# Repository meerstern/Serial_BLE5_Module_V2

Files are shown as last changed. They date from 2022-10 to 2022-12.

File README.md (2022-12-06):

# BLE5モジュール変換基板V2 
Serial_BLE5_Module_V2 is Lyra P module board with Wireless Xpress Firm.  

## 概要 
  * Laird Connectivity社製のBLEモジュール、Lyra Pを搭載した変換基板です  
  * Silicon Labs社のBGXシリーズで採用されていたWireless Xpress互換ファームを出荷時に書き込んでいます  
  * Wireless Xpress互換ファームで簡易なUARTコマンドを用いてBluetooh通信を使用できます  
  * スマートフォンや他のWireless Xpressモジュールと容易に接続することが可能です  
  * [Wireless Xpressファームの他、AT Command Setファーム][7]や開発環境によるカスタムファームを利用できます  
  * ファームの書き換えはUSBシリアルUART変換アダプタ(CTS,RTS接続必須)等を介して書き換えできます  
  * 電源電圧範囲1.8V~3.8V  
  * 3.3Vシリアル通信(UART,初期115200bps)で外部機器からパラメータを設定できます  
  * 3.3Vシリアル通信はGROVEコネクタ互換でも接続できます  
  * BGX13Pを使用した[BLE5モジュール変換基板][6]と同じピンアサインとサイズです  
  * TELEC(技適)認証済 工事設計認証番号 [209-J00456][5]  
  * 基板サイズ25mm x25mm(Grove互換コネクタ突起部除く)  

## 販売サイト
  * [スイッチサイエンス][8]

## 関連情報
 * [データシート][1]
 * [Laird Connectivity社 Lyra P製品サイト][2]
 * Wireless Xpressマクニカ製品紹介サイト[その１][3]、[その２][4]  

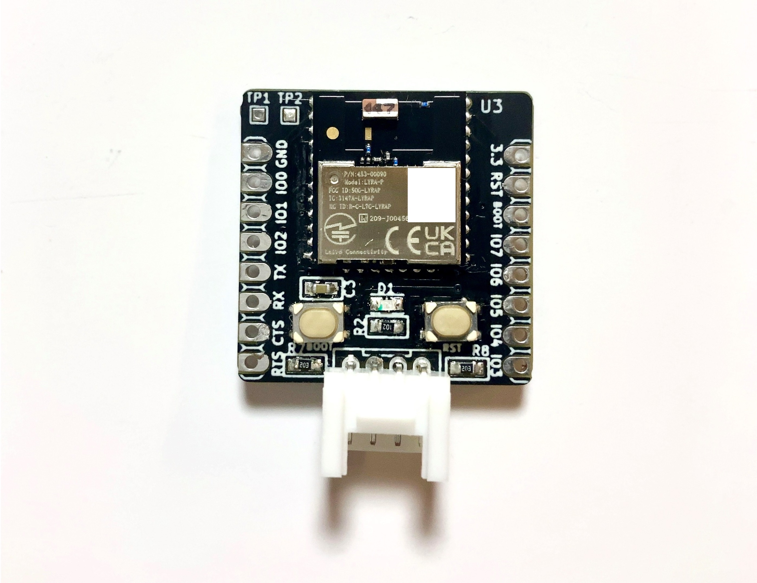
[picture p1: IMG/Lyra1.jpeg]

   
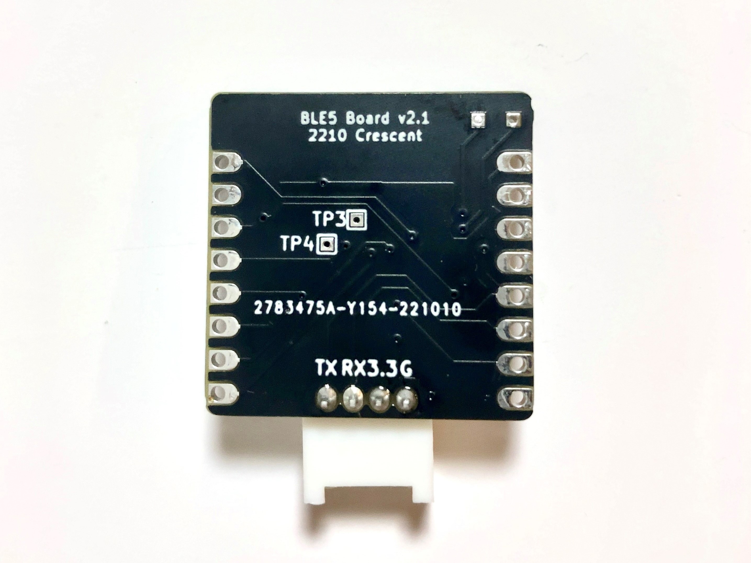
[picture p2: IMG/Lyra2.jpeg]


[1]: https://www.lairdconnect.com/documentation/datasheet-lyra-p
[2]: https://www.lairdconnect.com/wireless-modules/bluetooth-modules/bluetooth-5-modules/lyra-series-bluetooth-53-modules

[3]: https://service.macnica.co.jp/library/130293
[4]: https://service.macnica.co.jp/library/130269
[5]: https://www.tele.soumu.go.jp/giteki/SearchServlet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*****
[6]: https://github.com/meerstern/Serial_BLE5_Module
[7]: https://github.com/LairdCP/Lyra_Firmware
[8]: https://www.switch-science.com/products/8649

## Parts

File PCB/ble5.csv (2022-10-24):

ID | 参照記号 | パッケージ | 数 | 名称 | Supplier and ref
1 | U3 | bgm13p-smd | 1 | LyraP
2 | CLK | TestPoint_THTPad_1.0x1.0mm_Drill0.5mm | 1 | SWCLK
3 | DIO | TestPoint_THTPad_1.0x1.0mm_Drill0.5mm | 1 | SWDIO
4 | C3 | C-0603 | 1 | 0.1u
5 | R2 | R-0603 | 1 | 1k
6 | D1 | generic-LED1608 | 1 | LED
7 | P1,P2 | pinhead-1X08 | 2 | CONN_01X08
8 | R7,R8 | R-0603 | 2 | 20k
9 | SW1,SW2 | SKRPACE010 | 2 | SW_Push
10 | P3 | GROVE | 1 | CONN_01X04

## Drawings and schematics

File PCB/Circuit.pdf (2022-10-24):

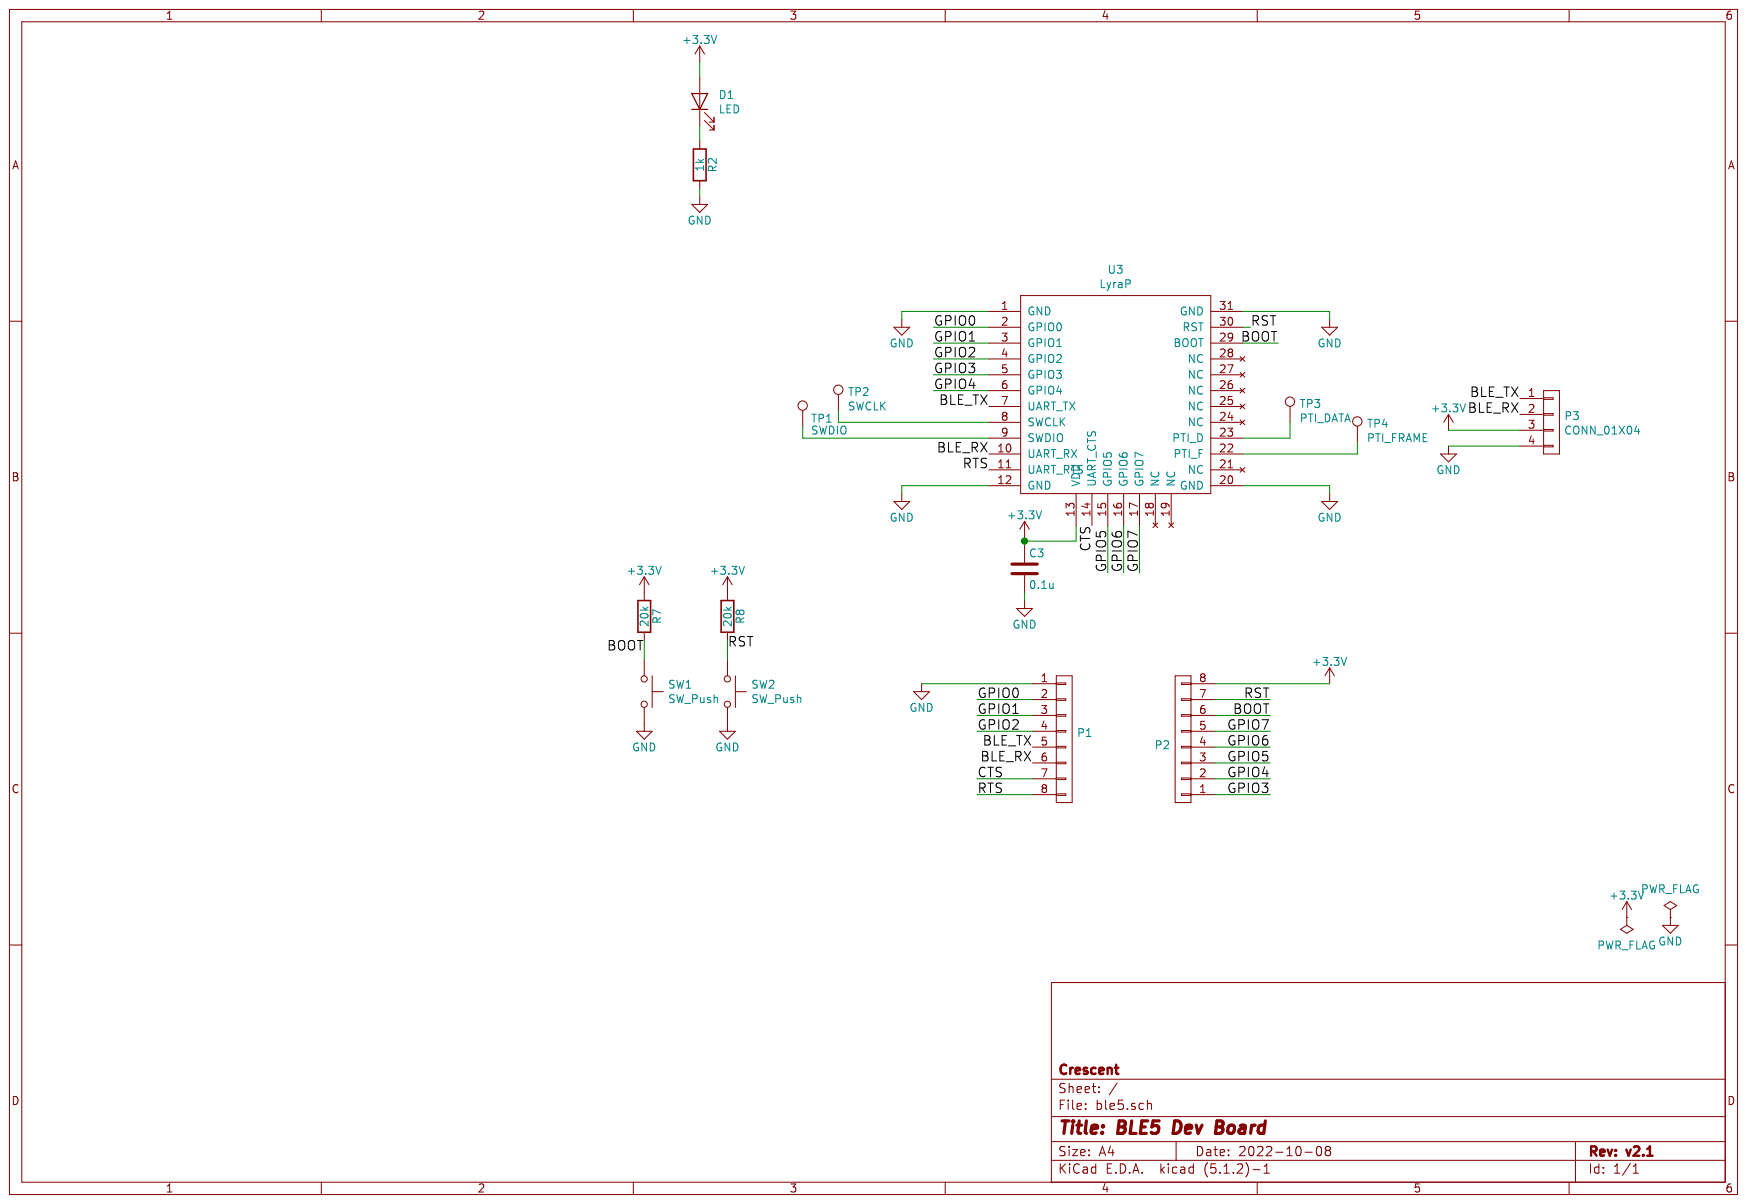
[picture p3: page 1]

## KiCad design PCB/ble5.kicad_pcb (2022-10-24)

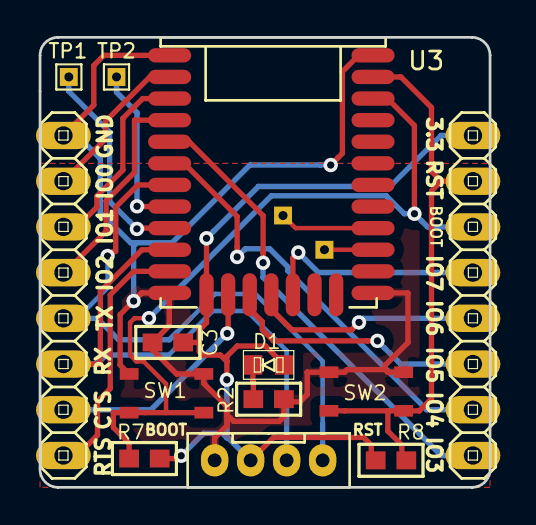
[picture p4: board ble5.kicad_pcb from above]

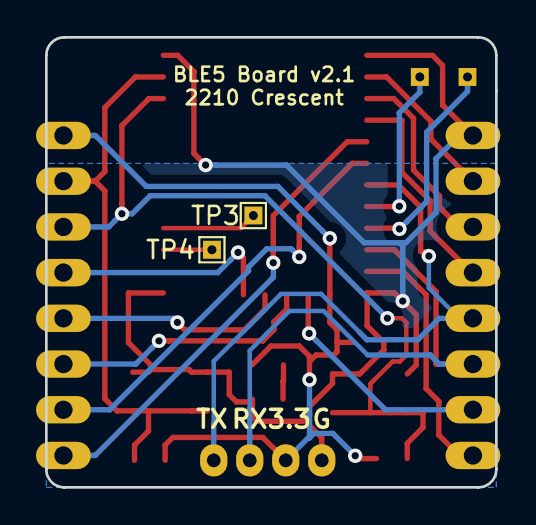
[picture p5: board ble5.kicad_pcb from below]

Board: 2 copper layers, 25.0 x 25.0 mm, 15 parts (2 on the bottom side), 21 nets.

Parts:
C3: 0.1u; C-0603
D1: LED; generic-LED1608
P1, P2: CONN_01X08; pinhead-1X08
P3: CONN_01X04; GROVE
R2: 1k; R-0603
R7, R8: 20k; R-0603
SW1, SW2: SW_Push; SKRPACE010
TP1: SWDIO; TestPoint_THTPad_1.0x1.0mm_Drill0.5mm
TP2: SWCLK; TestPoint_THTPad_1.0x1.0mm_Drill0.5mm
TP3: PTI_DATA; TestPoint_THTPad_1.0x1.0mm_Drill0.5mm
TP4: PTI_FRAME; TestPoint_THTPad_1.0x1.0mm_Drill0.5mm
U3: LyraP; bgm13p-smd

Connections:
+3V3: C3.1, D1.A, P2.8, P3.3, R7.1, R8.1, U3.13
/BLE_RX: P1.6, P3.2, U3.10
/BLE_TX: P1.5, P3.1, U3.7
/BOOT: P2.6, R7.2, SW1.1, U3.29
/CTS: P1.7, U3.14
/GPIO0: P1.2, U3.2
/GPIO1: P1.3, U3.3
/GPIO2: P1.4, U3.4
/GPIO3: P2.1, U3.5
/GPIO4: P2.2, U3.6
/GPIO5: P2.3, U3.15
/GPIO6: P2.4, U3.16
/GPIO7: P2.5, U3.17
/RST: P2.7, R8.2, SW2.1, U3.30
/RTS: P1.8, U3.11
GND: C3.2, P1.1, P3.4, R2.2, SW1.2, SW2.2, U3.1, U3.12, U3.20, U3.31
unnamed: D1.K, R2.1
unnamed: TP1.1, U3.9
unnamed: TP2.1, U3.8
unnamed: TP3.1, U3.23
unnamed: TP4.1, U3.22
